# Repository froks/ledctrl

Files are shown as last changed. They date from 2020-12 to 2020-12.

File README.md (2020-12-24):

# ledctrlv2.1

ledctrl is a 24-channel controller for led-strips - it uses a stm32f407 to pwm-control 12x QS6K1 MOSFETs for the channels, and a microsd-card slot to store animation/program data.

Prototypes were built and were working, but the project didn't progress any further and was abandoned. 

The modified micropython-version with the custom mappings is missing, but could be easily recreated.

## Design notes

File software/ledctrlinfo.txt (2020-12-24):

missing: firmware modification of micropython

pin layout
ledctrl v2.1

right side:
o  o PWM8  PWM16
o  o PWM7  PWM15
o  o PWM6  PWM14
o  o PWM5  PWM13
o  o Vbat  Vbat
o  o PWM4  PWM12
o  o PWM3  PWM11
o  o PWM2  PWM10
o  o PWM1  PWM9
o  o Vbat  Vbat

left side:
o  o ADC2  ADC3
o  o SCLK  ADC1
o  o GND   GND
o  o MISO  RX  
o  o MOSI  TX  
o  o PWM20 PWM24
o  o PWM19 PWM23
o  o PWM18 PWM22
o  o PWM17 PWM21
o  o Vbat  Vbat

# ohne Pin('CH3') und mit p = Pin('CH3', mode=Pin.AF_PP, af=AF_TIM1)

from pyb import Pin, Timer
tim1 = Timer(1, freq=1000)
tim2 = Timer(2, freq=1000)
tim4 = Timer(4, freq=1000)
tim5 = Timer(5, freq=1000)
tim8 = Timer(8, freq=1000)
tim9 = Timer(9, freq=1000)
tim10 = Timer(10, freq=1000)
tim11 = Timer(11, freq=1000)
tim12 = Timer(12, freq=1000)

ch_pins = []
ch_pins.append(Pin('CH1', mode=Pin.AF_PP, af=Pin.AF2_TIM5))
ch_pins.append(Pin('CH2', mode=Pin.AF_PP, af=Pin.AF2_TIM5))
ch_pins.append(Pin('CH3', mode=Pin.AF_PP, af=Pin.AF1_TIM1)) 
ch_pins.append(Pin('CH4', mode=Pin.AF_PP, af=Pin.AF1_TIM1)) 
ch_pins.append(Pin('CH5', mode=Pin.AF_PP, af=Pin.AF9_TIM12)) 
ch_pins.append(Pin('CH6', mode=Pin.AF_PP, af=Pin.AF9_TIM12)) 
ch_pins.append(Pin('CH7', mode=Pin.AF_PP, af=Pin.AF2_TIM4)) 
ch_pins.append(Pin('CH8', mode=Pin.AF_PP, af=Pin.AF3_TIM8)) 
ch_pins.append(Pin('CH9', mode=Pin.AF_PP, af=Pin.AF1_TIM1)) 
ch_pins.append(Pin('CH10', mode=Pin.AF_PP, af=Pin.AF1_TIM1)) 
ch_pins.append(Pin('CH11', mode=Pin.AF_PP, af=Pin.AF1_TIM2)) 
ch_pins.append(Pin('CH12', mode=Pin.AF_PP, af=Pin.AF1_TIM2)) 
ch_pins.append(Pin('CH13', mode=Pin.AF_PP, af=Pin.AF2_TIM4)) 
ch_pins.append(Pin('CH14', mode=Pin.AF_PP, af=Pin.AF2_TIM4)) 
ch_pins.append(Pin('CH15', mode=Pin.AF_PP, af=Pin.AF2_TIM4)) 
ch_pins.append(Pin('CH16', mode=Pin.AF_PP, af=Pin.AF3_TIM8)) 
ch_pins.append(Pin('CH17', mode=Pin.AF_PP, af=Pin.AF2_TIM5)) 
ch_pins.append(Pin('CH18', mode=Pin.AF_PP, af=Pin.AF3_TIM9))
ch_pins.append(Pin('CH19', mode=Pin.AF_PP, af=Pin.AF3_TIM11))
ch_pins.append(Pin('CH20', mode=Pin.AF_PP, af=Pin.AF1_TIM2)) 
ch_pins.append(Pin('CH21', mode=Pin.AF_PP, af=Pin.AF2_TIM5)) 
ch_pins.append(Pin('CH22', mode=Pin.AF_PP, af=Pin.AF3_TIM9)) 
ch_pins.append(Pin('CH23', mode=Pin.AF_PP, af=Pin.AF3_TIM10)) 
ch_pins.append(Pin('CH24', mode=Pin.AF_PP, af=Pin.AF1_TIM2))

ch1 = tim5.channel(3, Timer.PWM);
ch2 = tim5.channel(4, Timer.PWM);
ch3 = tim1.channel(3, Timer.PWM);
ch4 = tim1.channel(4, Timer.PWM);
ch5 = tim12.channel(1, Timer.PWM);
ch6 = tim12.channel(2, Timer.PWM);
ch7 = tim4.channel(3, Timer.PWM);
ch8 = tim8.channel(1, Timer.PWM);
ch9 = tim1.channel(1, Timer.PWM);
ch10 = tim1.channel(2, Timer.PWM);
ch11 = tim2.channel(3, Timer.PWM);
ch12 = tim2.channel(4, Timer.PWM);
ch13 = tim4.channel(1, Timer.PWM);
ch14 = tim4.channel(2, Timer.PWM);
ch15 = tim4.channel(4, Timer.PWM);
ch16 = tim8.channel(2, Timer.PWM);
ch17 = tim5.channel(1, Timer.PWM);
ch18 = tim9.channel(1, Timer.PWM);
ch19 = tim11.channel(1, Timer.PWM);
ch20 = tim2.channel(2, Timer.PWM);
ch21 = tim5.channel(2, Timer.PWM);
ch22 = tim9.channel(2, Timer.PWM);
ch23 = tim10.channel(1, Timer.PWM);
ch24 = tim2.channel(1, Timer.PWM);

_CH1  - PA2, TIM5, CH3
_CH2  - PA3, TIM5, CH4
_CH3  - PE13, TIM1, CH3
_CH4  - PE14, TIM1, CH4
_CH5  - PB14, TIM12, CH1
_CH6  - PB15, TIM12, CH2
_CH7  - PD14, TIM4, CH3
_CH8  - PC6, TIM8, CH1
_CH9  - PE9, TIM1, CH1
_CH10 - PE11, TIM1, CH2 
_CH11 - PB10, TIM2, CH3
_CH12 - PB11, TIM2, CH4
_CH13 - PB1, TIM4, CH1
_CH14 - PD13, TIM4, CH2
_CH15 - PD15, TIM4, CH4
_CH16 - PC7, TIM8, CH2
_CH17 - PA0, TIM5, CH1
_CH18 - PE5, TIM9, CH1
_CH19 - PB9, TIM11, CH1
_CH20 - PB3, TIM2, CH2
_CH21 - PA1, TIM5, CH1
CH22 - PE6, TIM9, CH2
CH23 - PB8, TIM10, CH1
CH24 - PA15, TIM2, CH1

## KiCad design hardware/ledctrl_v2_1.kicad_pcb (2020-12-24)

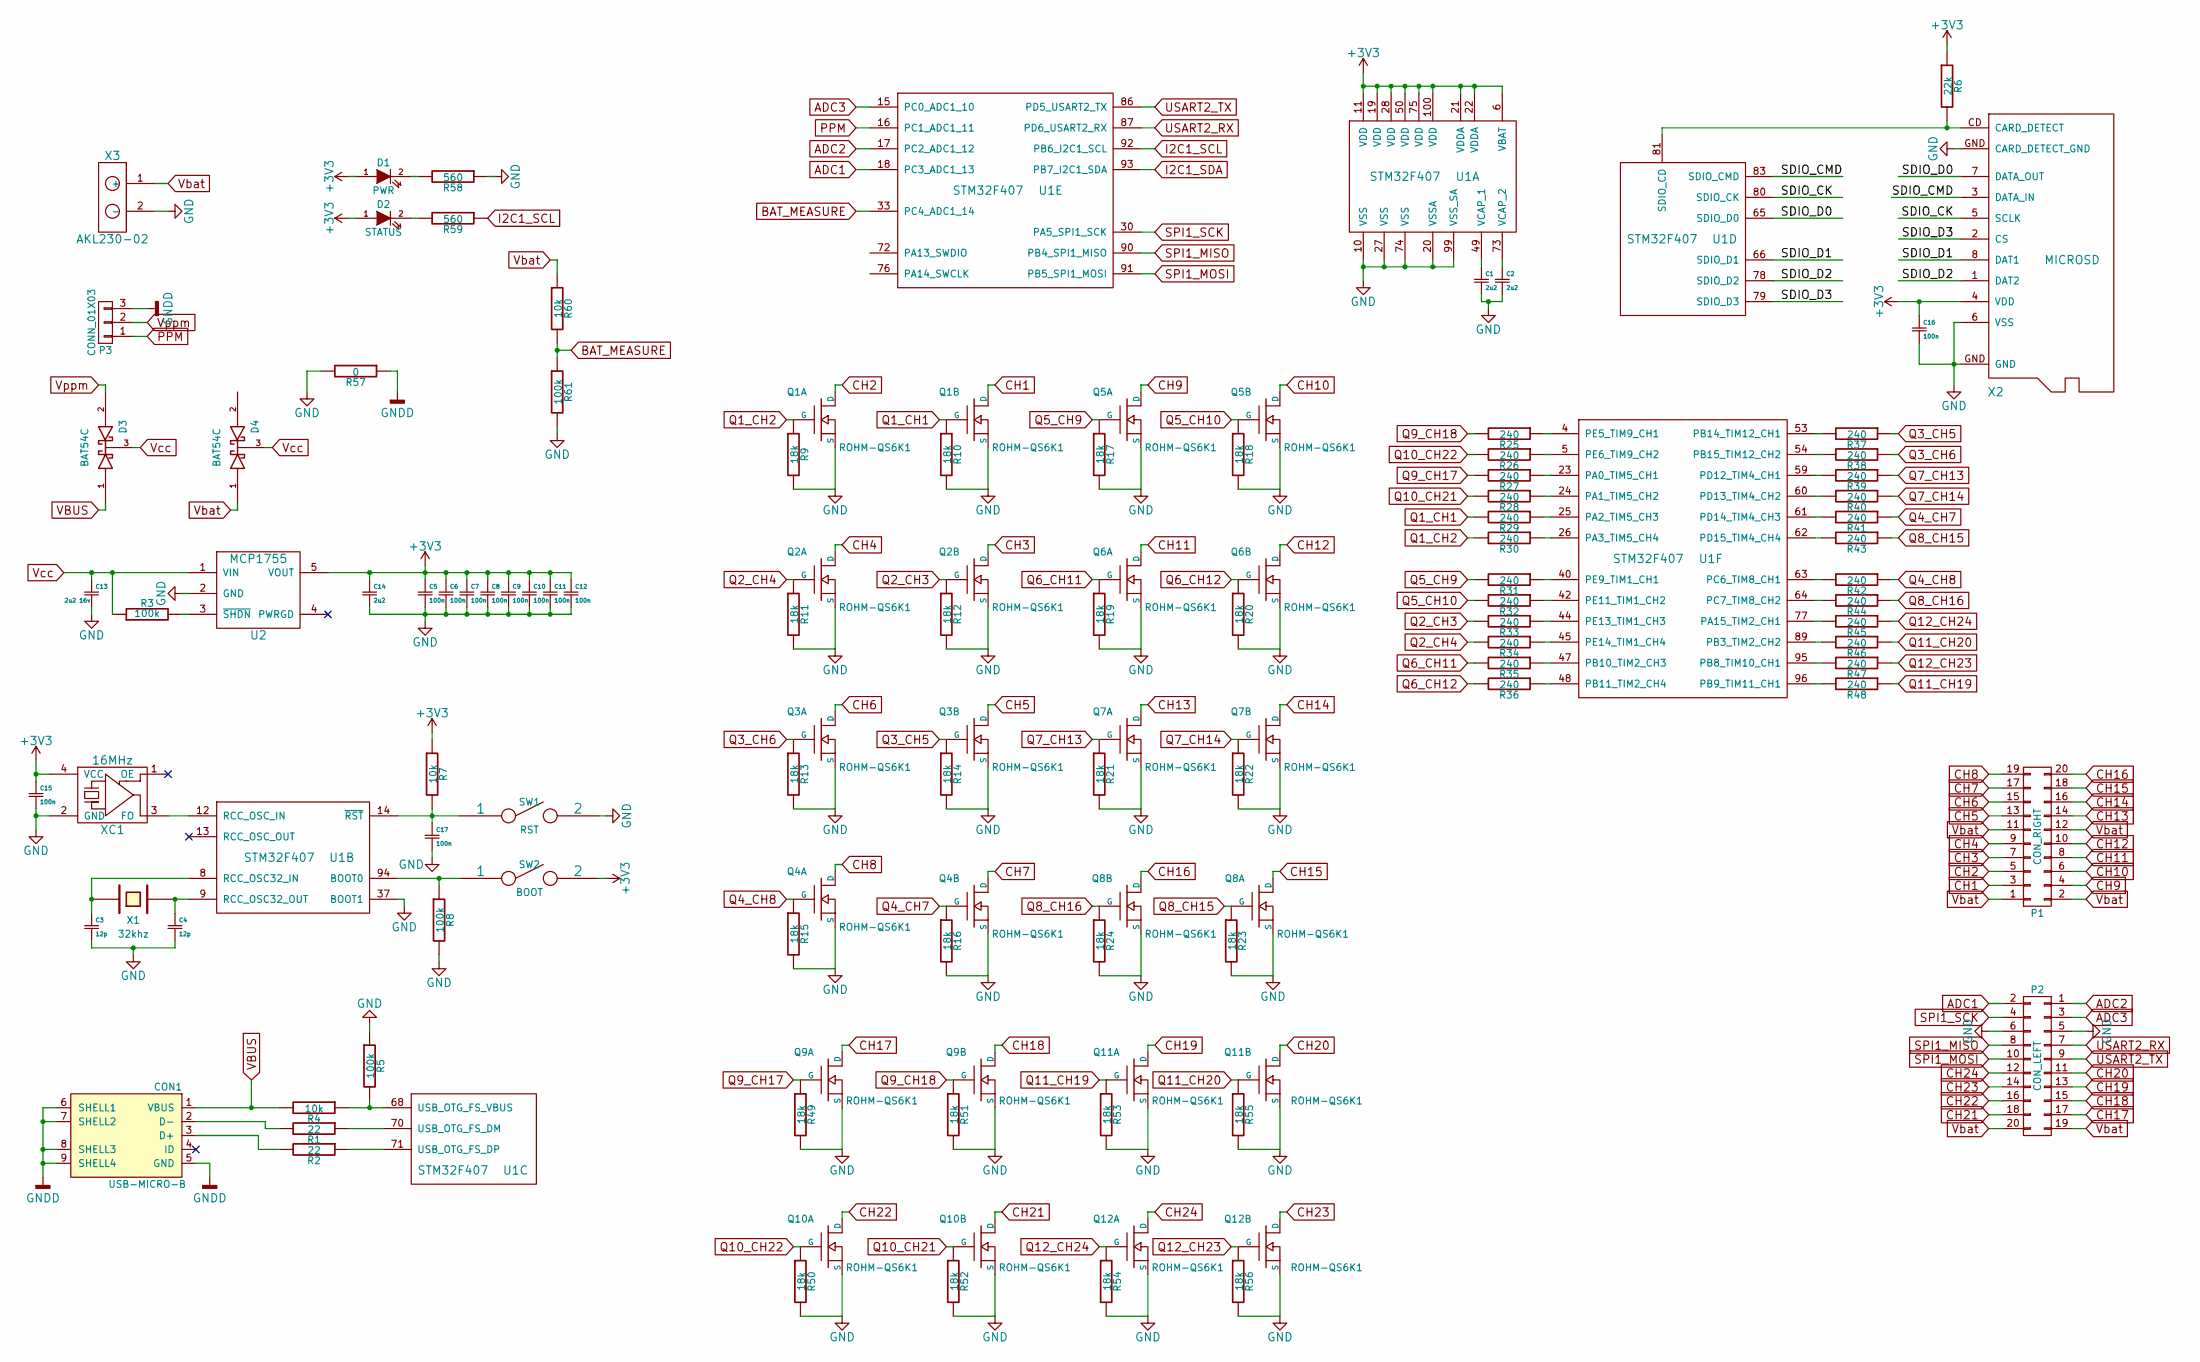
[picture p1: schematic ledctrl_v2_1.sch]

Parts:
C1, C2, C14: 2u2; C_0603
C3, C4: 12p; C_0402
C5, C6, C7, C8, C9, C10, C11, C12, C15, C16, C17: 100n; C_0402
C13: 2u2 16v; C_0603
CON1: USB-MICRO-B; MOLEX_473460001
D1: PWR; LED-0603
D2: STATUS; LED-0603
D3, D4: BAT54C; SOT-23
P1: CON_RIGHT; CON_10x2_SIDEWAYS
P2: CON_LEFT; CON_10x2_SIDEWAYS
P3: CONN_01X03; Pin_Header_Angled_1x03
Q1, Q2, Q3, Q4, Q5, Q6, Q7, Q8, Q9, Q10, Q11, Q12: ROHM-QS6K1; TSMT6
R1, R2: 22; R_0402
R3, R5, R8, R61: 100k; R_0402
R4, R7, R60: 10k; R_0402
R6: 22k; R_0402
R9, R10, R11, R12, R13, R14, R15, R16, R17, R18, R19, R20, R21, R22, R23, R24, R49, R50, R51, R52, R53, R54, R55, R56: 18k; R_0402
R25, R26, R27, R28, R29, R30, R31, R32, R33, R34, R35, R36, R37, R38, R39, R40, R41, R42, R43, R44, R45, R46, R47, R48: 240; R_0402
R57: 0; R_0603
R58, R59: 560; R_0402
SW1: RST; TE_1977066-1
SW2: BOOT; TE_1977066-1
U1: STM32F407; LQFP-100_14x14mm_Pitch0.5mm
U2: MCP1755; SOT23-5
X1: 32khz; FC-135
X2: MICROSD; AMP_101-00660-68-6
X3: AKL230-02; AKL235-02_XT60
XC1: 16MHz; ASDMB

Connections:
+3V3: C5.1, C6.1, C7.1, C8.1, C9.1, C10.1, C11.1, C12.1, C14.1, C15.1, C16.1, D1.1 (A), D2.1 (A), R6.1, R7.1, SW2.2, U1.6 (VBAT), U1.11 (VDD), U1.19 (VDD), U1.21 (VDDA), U1.22 (VDDA), U1.28 (VDD), U1.50 (VDD), U1.75 (VDD), U1.100 (VDD), U2.5 (VOUT), X2.4 (VDD), XC1.4 (VCC)
/SDIO_CK: U1.80 (SDIO_CK), X2.5 (SCLK)
/SDIO_CMD: U1.83 (SDIO_CMD), X2.3 (DATA_IN)
/SDIO_D0: U1.65 (SDIO_D0), X2.7 (DATA_OUT)
/SDIO_D1: U1.66 (SDIO_D1), X2.8 (DAT1)
/SDIO_D2: U1.78 (SDIO_D2), X2.1 (DAT2)
/SDIO_D3: U1.79 (SDIO_D3), X2.2 (CS)
ADC1: P2.2, U1.18 (PC3_ADC1_13)
ADC2: P2.1, U1.17 (PC2_ADC1_12)
ADC3: P2.3, U1.15 (PC0_ADC1_10)
BAT_MEASURE: R60.2, R61.1, U1.33 (PC4_ADC1_14)
CH1: P1.3, Q1.4 (D)
CH2: P1.5, Q1.6 (D)
CH3: P1.7, Q2.4 (D)
CH4: P1.9, Q2.6 (D)
CH5: P1.13, Q3.4 (D)
CH6: P1.15, Q3.6 (D)
CH7: P1.17, Q4.4 (D)
CH8: P1.19, Q4.6 (D)
CH9: P1.4, Q5.6 (D)
CH10: P1.6, Q5.4 (D)
CH11: P1.8, Q6.6 (D)
CH12: P1.10, Q6.4 (D)
CH13: P1.14, Q7.6 (D)
CH14: P1.16, Q7.4 (D)
CH15: P1.18, Q8.6 (D)
CH16: P1.20, Q8.4 (D)
CH17: P2.17, Q9.6 (D)
CH18: P2.15, Q9.4 (D)
CH19: P2.13, Q11.6 (D)
CH20: P2.11, Q11.4 (D)
CH21: P2.18, Q10.4 (D)
CH22: P2.16, Q10.6 (D)
CH23: P2.14, Q12.4 (D)
CH24: P2.12, Q12.6 (D)
GND: C1.2, C2.2, C3.2, C4.2, C5.2, C6.2, C7.2, C8.2, C9.2, C10.2, C11.2, C12.2, C13.2, C14.2, C15.2, C16.2, C17.2, P2.5, P2.6, Q1.2 (S), Q1.5 (S), Q2.2 (S), Q2.5 (S), Q3.2 (S), Q3.5 (S), Q4.2 (S), Q4.5 (S), Q5.2 (S), Q5.5 (S), Q6.2 (S), Q6.5 (S), Q7.2 (S), Q7.5 (S), Q8.2 (S), Q8.5 (S), Q9.2 (S), Q9.5 (S), Q10.2 (S), Q10.5 (S), Q11.2 (S), Q11.5 (S), Q12.2 (S), Q12.5 (S), R5.1, R8.2, R9.2, R10.2, R11.2, R12.2, R13.2, R14.2, R15.2, R16.2, R17.2, R18.2, R19.2, R20.2, R21.2, R22.2, R23.2, R24.2, R49.2, R50.2, R51.2, R52.2, R53.2, R54.2, R55.2, R56.2, R57.2, R58.1, R61.2, SW1.2, U1.10 (VSS), U1.20 (VSSA), U1.27 (VSS), U1.37 (BOOT1), U1.74 (VSS), U1.99 (VSS_SA), U2.2 (GND), X2.6 (VSS), X2.GND (CARD_DETECT_GND), X3.2 (-), XC1.2 (GND)
GNDD: CON1.5 (GND), CON1.6 (SHELL1), CON1.7 (SHELL2), CON1.8 (SHELL3), CON1.9 (SHELL4), P3.3, R57.1
I2C1_SCL: R59.1, U1.92 (PB6_I2C1_SCL)
I2C1_SDA: U1.93 (PB7_I2C1_SDA)
unnamed: C1.1, U1.49 (VCAP_1)
unnamed: C2.1, U1.73 (VCAP_2)
unnamed: C3.1, U1.8 (RCC_OSC32_IN), X1.1
unnamed: C4.1, U1.9 (RCC_OSC32_OUT), X1.2
unnamed: C17.1, R7.2, SW1.1, U1.14 (~RST)
unnamed: CON1.2 (D-), R1.2
unnamed: CON1.3 (D+), R2.2
unnamed: D1.2 (K), R58.2
unnamed: D2.2 (K), R59.2
unnamed: R1.1, U1.70 (USB_OTG_FS_DM)
unnamed: R2.1, U1.71 (USB_OTG_FS_DP)
unnamed: R3.2, U2.3 (~SHDN)
unnamed: R4.1, R5.2, U1.68 (USB_OTG_FS_VBUS)
unnamed: R6.2, U1.81 (SDIO_CD), X2.CD (CARD_DETECT)
unnamed: R8.1, SW2.1, U1.94 (BOOT0)
unnamed: R25.1, U1.4 (PE5_TIM9_CH1)
unnamed: R26.1, U1.5 (PE6_TIM9_CH2)
unnamed: R27.1, U1.23 (PA0_TIM5_CH1)
unnamed: R28.1, U1.24 (PA1_TIM5_CH2)
unnamed: R29.1, U1.25 (PA2_TIM5_CH3)
unnamed: R30.1, U1.26 (PA3_TIM5_CH4)
unnamed: R31.1, U1.40 (PE9_TIM1_CH1)
unnamed: R32.1, U1.42 (PE11_TIM1_CH2)
unnamed: R33.1, U1.44 (PE13_TIM1_CH3)
unnamed: R34.1, U1.45 (PE14_TIM1_CH4)
unnamed: R35.1, U1.47 (PB10_TIM2_CH3)
unnamed: R36.1, U1.48 (PB11_TIM2_CH4)
unnamed: R37.2, U1.53 (PB14_TIM12_CH1)
unnamed: R38.2, U1.54 (PB15_TIM12_CH2)
unnamed: R39.2, U1.59 (PD12_TIM4_CH1)
unnamed: R40.2, U1.60 (PD13_TIM4_CH2)
unnamed: R41.2, U1.61 (PD14_TIM4_CH3)
unnamed: R42.2, U1.63 (PC6_TIM8_CH1)
unnamed: R43.2, U1.62 (PD15_TIM4_CH4)
unnamed: R44.2, U1.64 (PC7_TIM8_CH2)
unnamed: R45.2, U1.77 (PA15_TIM2_CH1)
unnamed: R46.2, U1.89 (PB3_TIM2_CH2)
unnamed: R47.2, U1.95 (PB8_TIM10_CH1)
unnamed: R48.2, U1.96 (PB9_TIM11_CH1)
unnamed: U1.12 (RCC_OSC_IN), XC1.3 (FO)
PPM: P3.1, U1.16 (PC1_ADC1_11)
Q1_CH1: Q1.3 (G), R10.1, R29.2
Q1_CH2: Q1.1 (G), R9.1, R30.2
Q2_CH3: Q2.3 (G), R12.1, R33.2
Q2_CH4: Q2.1 (G), R11.1, R34.2
Q3_CH5: Q3.3 (G), R14.1, R37.1
Q3_CH6: Q3.1 (G), R13.1, R38.1
Q4_CH7: Q4.3 (G), R16.1, R41.1
Q4_CH8: Q4.1 (G), R15.1, R42.1
Q5_CH9: Q5.1 (G), R17.1, R31.2
Q5_CH10: Q5.3 (G), R18.1, R32.2
Q6_CH11: Q6.1 (G), R19.1, R35.2
Q6_CH12: Q6.3 (G), R20.1, R36.2
Q7_CH13: Q7.1 (G), R21.1, R39.1
Q7_CH14: Q7.3 (G), R22.1, R40.1
Q8_CH15: Q8.1 (G), R23.1, R43.1
Q8_CH16: Q8.3 (G), R24.1, R44.1
Q9_CH17: Q9.1 (G), R27.2, R49.1
Q9_CH18: Q9.3 (G), R25.2, R51.1
Q10_CH21: Q10.3 (G), R28.2, R52.1
Q10_CH22: Q10.1 (G), R26.2, R50.1
Q11_CH19: Q11.1 (G), R48.1, R53.1
Q11_CH20: Q11.3 (G), R46.1, R55.1
Q12_CH23: Q12.3 (G), R47.1, R56.1
Q12_CH24: Q12.1 (G), R45.1, R54.1
SPI1_MISO: P2.8, U1.90 (PB4_SPI1_MISO)
SPI1_MOSI: P2.10, U1.91 (PB5_SPI1_MOSI)
SPI1_SCK: P2.4, U1.30 (PA5_SPI1_SCK)
USART2_RX: P2.7, U1.87 (PD6_USART2_RX)
USART2_TX: P2.9, U1.86 (PD5_USART2_TX)
VBUS: CON1.1 (VBUS), D3.1 (Anode), R4.2
Vbat: D4.1 (Anode), P1.1, P1.2, P1.11, P1.12, P2.19, P2.20, R60.1, X3.1 (+)
Vcc: C13.1, D3.3 (AK), D4.3 (AK), R3.1, U2.1 (VIN)
Vppm: D3.2 (cathode), P3.2

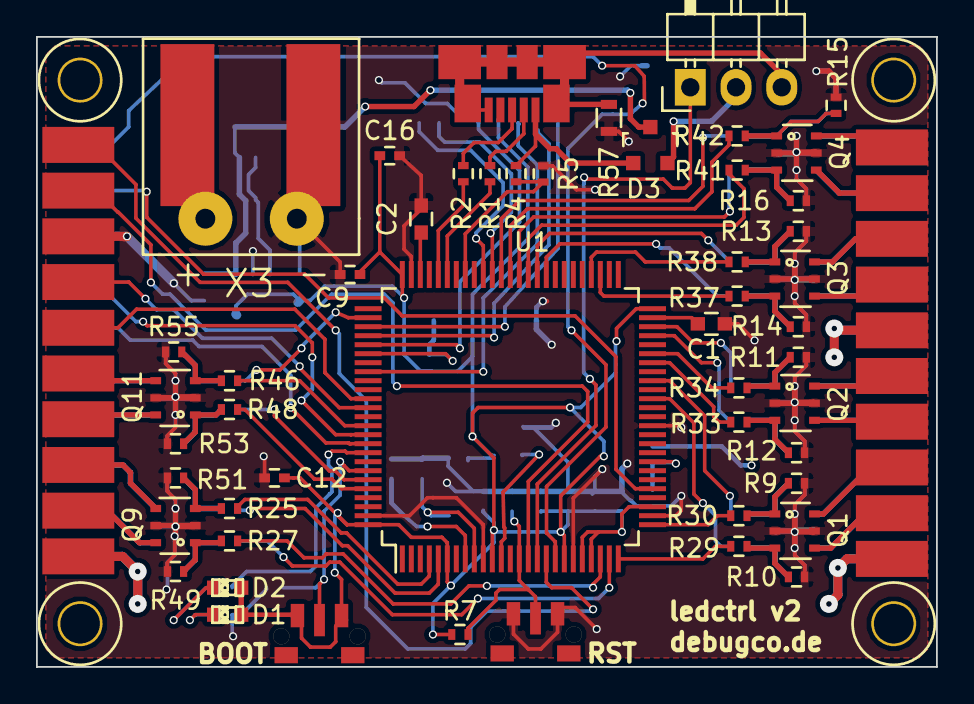
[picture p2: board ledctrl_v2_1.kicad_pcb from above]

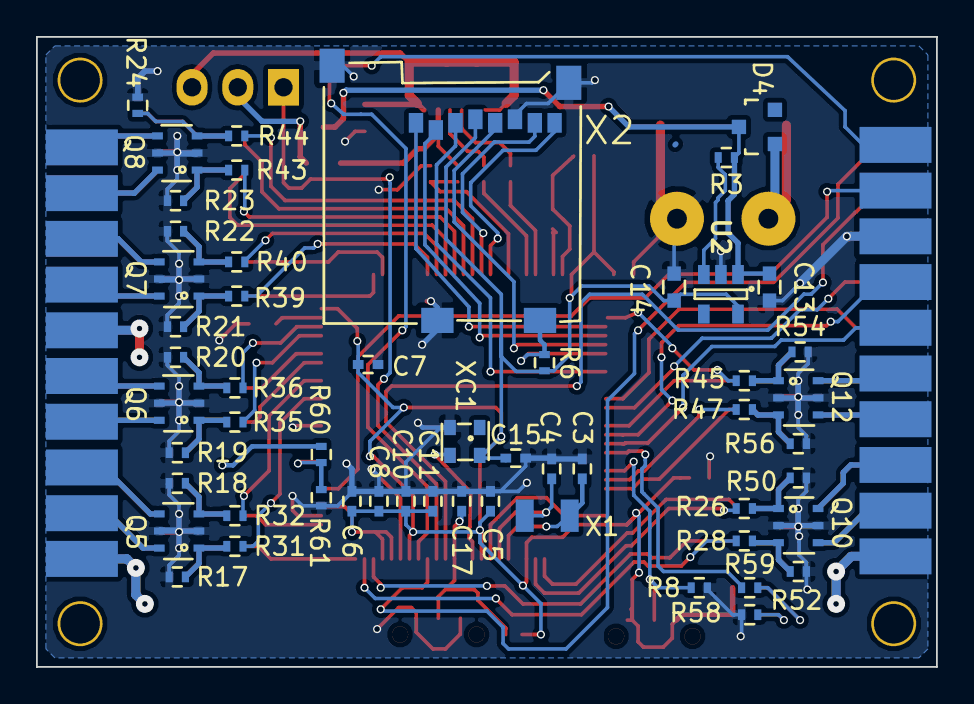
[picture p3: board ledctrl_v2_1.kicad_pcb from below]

Board: 4 copper layers, 50.0 x 35.0 mm, 107 parts (54 on the bottom side), 112 nets.

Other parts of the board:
1pin: VAL**; 1pin
